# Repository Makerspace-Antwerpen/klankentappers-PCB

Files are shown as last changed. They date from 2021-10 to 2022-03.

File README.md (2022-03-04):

# klankentappers-PCB

## The goal
The goal of this project was to create a cheap mic pcb that can be used to measure soundlevels with inexpensive hardware. 
The PCB's shape is dictated by the housing. 

## The components
### INFINEON M69d120
This is your run of the mill PDM microphone. It was picked because of it's flat frequency response.
### ADAU 7002
This is a PDM to I2S converter chip. It converts the PDM signal of the microphone to a I2S signal that is usable by for example a raspberry pi or a variety of microcontrollers.

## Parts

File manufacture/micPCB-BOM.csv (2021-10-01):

Ref | Value | Footprint | Datasheet | Manufacturer | Vendor
C1 | 100nF | Capacitor_SMD:C_0402_1005Metric | ~
C2 | 0.1uF | Capacitor_SMD:C_0402_1005Metric | ~
J1 | Conn_01x02 | Connector_PinHeader_2.54mm:PinHeader_1x02_P2.54mm_Vertical | ~
J2 | Conn_01x03 | Connector_PinHeader_2.54mm:PinHeader_1x03_P2.54mm_Vertical | ~
J3 | Conn_01x02 | Connector_PinHeader_2.54mm:PinHeader_1x02_P2.54mm_Vertical | ~
MK1 | IM69D120 | Sensor_Audio:Infineon_PG-LLGA-5-1 | https://www.infineon.com/dgdl/Infineon-IM69D120-DS-v01_00-EN.pdf?fileId=5546d462602a9dc801607a0e41a01a2b
R1 | 4k7 | Resistor_SMD:R_0402_1005Metric | ~
R2 | 100 | Resistor_SMD:R_0402_1005Metric | ~
R3 | 0 | Resistor_SMD:R_0402_1005Metric | ~
R4 | 0 | Resistor_SMD:R_0402_1005Metric | ~
U1 | ADAU7002 | custom:BGA-8_2x4_0.8x1.6mm

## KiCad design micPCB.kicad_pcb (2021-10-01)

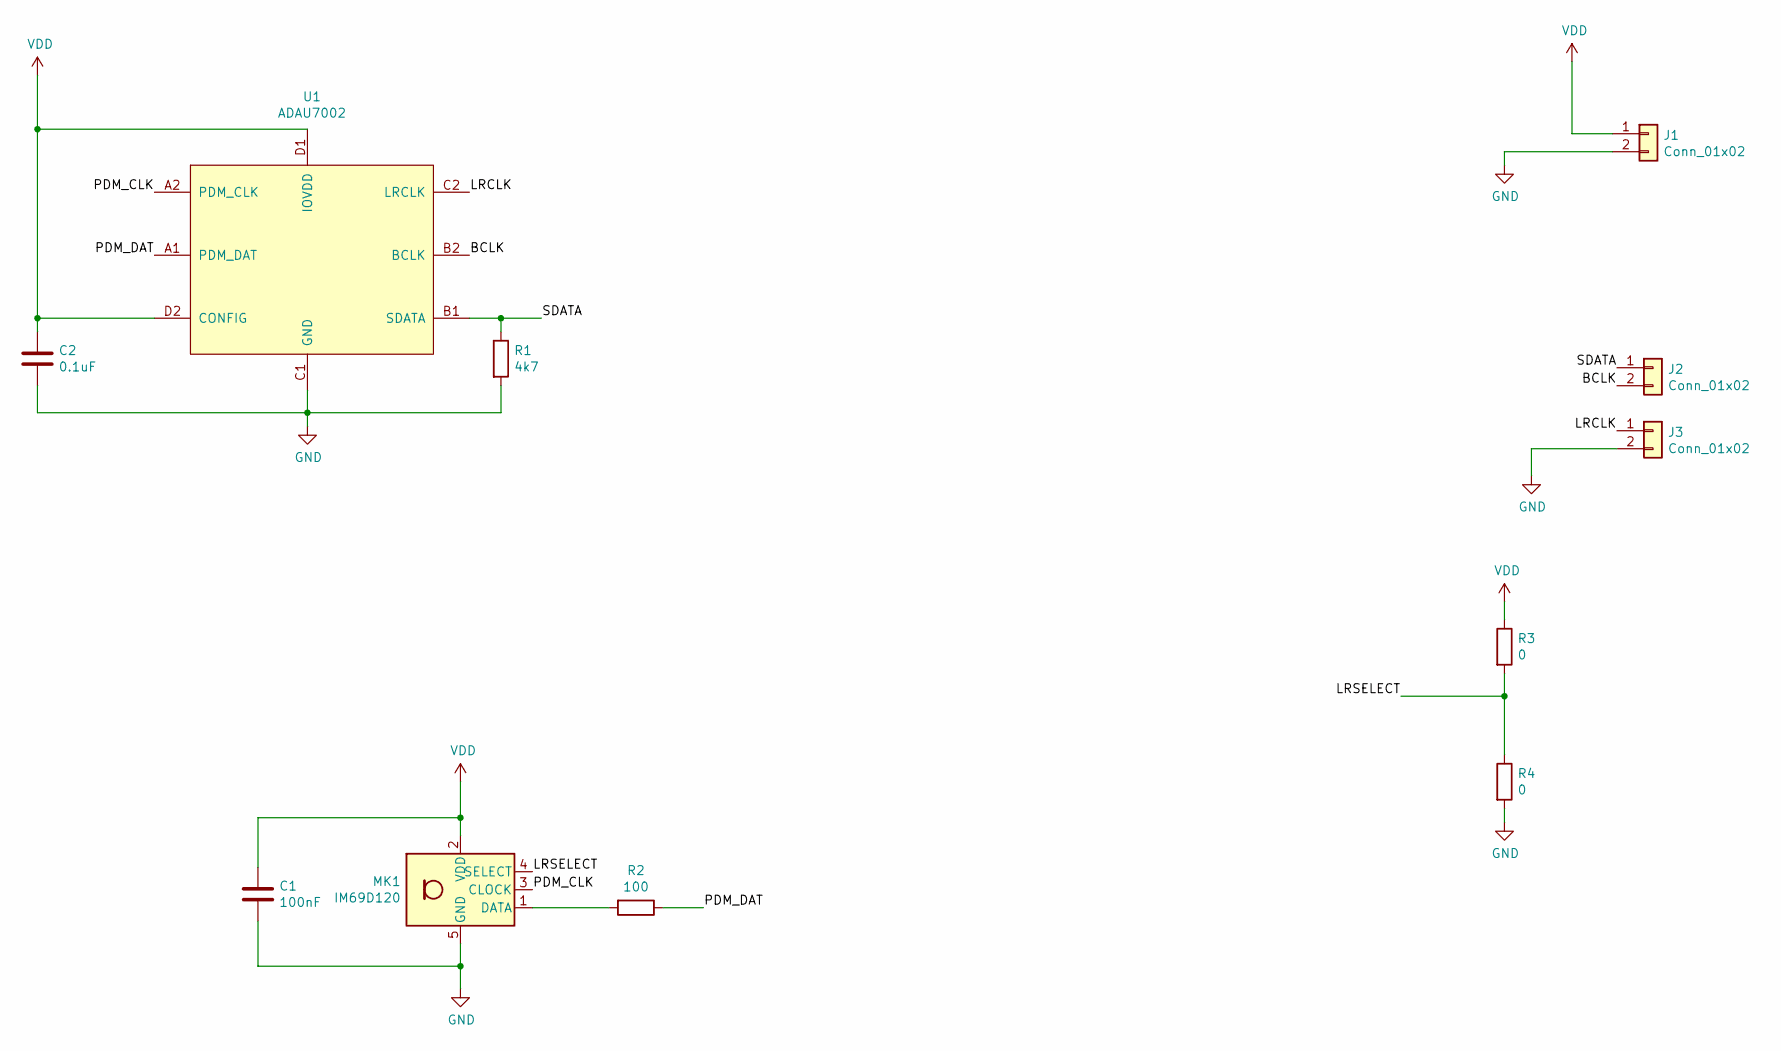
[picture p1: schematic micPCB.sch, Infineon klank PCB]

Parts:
C1: 100nF; C_0402_1005Metric; LCSC C1525
C2: 0.1uF; C_0402_1005Metric; LCSC C1525
J1, J2, J3: Conn_01x02; PinHeader_1x02_P2.54mm_Vertical_SMD_Pin1Right
MK1: IM69D120; Infineon_PG-LLGA-5-1
R1: 4k7; R_0402_1005Metric; LCSC C25900
R2: 100; R_0402_1005Metric; LCSC C25076
R3, R4: 0; R_0402_1005Metric
U1: ADAU7002; BGA-8_2x4_0.8x1.6mm

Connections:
/BCLK: J2.2, U1.B2 (BCLK)
/LRCLK: J3.1, U1.C2 (LRCLK)
/LRSELECT: MK1.4 (SELECT), R3.2, R4.1
/PDM_CLK: MK1.3 (CLOCK), U1.A2 (PDM_CLK)
/PDM_DAT: R2.1, U1.A1 (PDM_DAT)
/SDATA: J2.1, R1.1, U1.B1 (SDATA)
GND: C1.2, C2.2, J1.2, J3.2, MK1.5 (GND), R1.2, R4.2, U1.C1 (GND)
unnamed: MK1.1 (DATA), R2.2
VDD: C1.1, C2.1, J1.1, MK1.2 (VDD), R3.1, U1.D1 (IOVDD), U1.D2 (CONFIG)

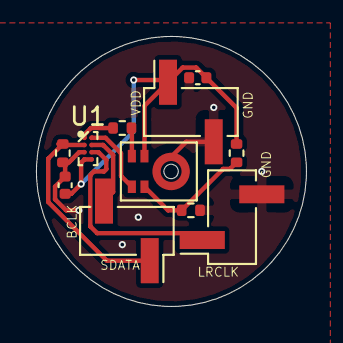
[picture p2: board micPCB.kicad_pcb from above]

Board: 2 copper layers, 15.0 x 15.0 mm, 11 parts (0 on the bottom side), 9 nets.
